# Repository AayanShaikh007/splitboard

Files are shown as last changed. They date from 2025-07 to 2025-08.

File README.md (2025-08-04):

# Splitboard
### A split keyboard modelled after the Ergodox with wireless connectivity

## What is the Splitboard?

The splitboard is a diy keyboard modelled after the Ergodox that has wireless bluetooth connectivity and on-board battery charging/management. The most striking thing about the keyboard is probably its distinct appearance compared to other keyboards, but hopefully this will add to the ergonomics of the keyboard. For this keyboard, I wanted to incorporate a number of features that I liked about my last keyboard, such as RGB lighting and Kalih hotswap sockets, while also adressing some of the issues with my last keyboard.


Typical Ergodox layout

## Why did I make the Splitboard?

I made the splitboard as a follow up to my original keyboard to address some mistakes I made in my last keyboard. Firstly, I made the case walls way too thick, at 1 cm, where in reality I only needed 2-4 mm. Additionally, I see now that the keyboard has a very large footprint on my desk and is difficult to move into a comfortable typing position. The splitboard consists of two, very portable halves that can be arranged around your desk in any way you want. Additionally, the case is much more asthetically appealing with low-profile walls (3mm) and a voronoi pattern on the bottom. Check out the product gallery to get a preview of the project.  

# Product Gallery












# BOM Table
| Item | Amount | Bought? | Cost (CAD) | Total Cost | Notes | Link |
|---|---|---|---|---|---|---|
| Adafruit Feather NRF52840 | 2 | n | 37.79 | 75.58 | | [AliExpress](https://www.aliexpress.com/item/1005009226053516.html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) |
| Switches (need 76) | 1 | n | 26.99 | 26.99 | | [Amazon](https://www.amazon.ca/Kailh-Mechanical-Keyboard-Switches-Bronze/dp/B078872V4C) |
| Kalih Sockets | 1 | n | 13.57 | 13.57 | | [AliExpress](https://www.aliexpress.com/item/1005007476614771.html) |
| Diodes | 1 | n | 11.36 | 11.36 | Possibly cheaper if bought with other stuff | [AliExpress](https://www.aliexpress.com/item/4000142272546.html) |
| SK6812mini-e | 1 | n | 8.04 | 8.04 | | [AliExpress](https://www.aliexpress.com/item/1005009217389452.html) |
| Keycaps | 1 | n | 29.99 | 29.99 | | [Amazon](https://www.amazon.ca/124-Key-Keycaps-Percent-Keyboard-Dye-Sub/dp/B09NRK5B3L) |
| PCB Manufacturing | 2 | n | 19.89 | 39.78 | $20 highway coupon (not applied) | — |
| Stabilizers | 1 | n | 7.29 | 7.29 | | [AliExpress](https://www.aliexpress.com/item/1005009141481219.html) |

| | | | | | | |
|---|---|---|---|---|---|---|
| | | | **CAD** | **USD** | | |
| **Total Cost**| | | 212.60 | 155.20  | Note: 150 USD = 204.58 CAD | |

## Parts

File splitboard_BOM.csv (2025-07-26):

Item | Amount | Bought? | Cost (CAD) | Total Cost | Notes | Link
Adafruit Feather NRF52840 | 2 | n | 37.79 | 75.58 |  | https://www.aliexpress.com/item/1005009226053516.html?src=bing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
Switches (need 76) | 1 | n | 26.99 | 26.99 |  | https://www.amazon.ca/Kailh-Mechanical-Keyboard-Switches-Bronze/dp/B078872V4C
Kalih Sockets | 1 | n | 13.57 | 13.57 |  | https://www.aliexpress.com/item/1005007476614771.html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
Diodes | 1 | n | 11.36 | 11.36 | possibly cheaper if bought with other stuff | https://www.aliexpress.com/item/4000142272546.html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
sk6812mini-e | 1 | n | 8.04 | 8.04 |  | https://www.aliexpress.com/item/1005009217389452.html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
Keycaps | 1 | n | 29.99 | 29.99 |  | https://www.amazon.ca/124-Key-Keycaps-Percent-Keyboard-Dye-Sub/dp/B09NRK5B3L?xpid=mhd-51rYrrEGe
PCB Manufacturing | 2 | n | 19.89 | 39.78 | 20 dollar highway coupon (not applied)
Stabilizers | 1 | n | 7.29 | 7.29 |  | https://www.aliexpress.com/item/1005009141481219.html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
 |  |  | CAD | USD
 |  | Total Cost | 212.60 | 155.198
 |  |  |  | Note: 150 USD = 204.58 CAD

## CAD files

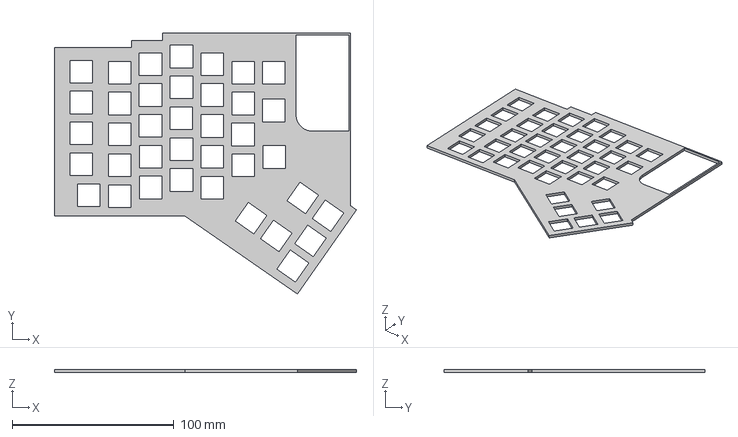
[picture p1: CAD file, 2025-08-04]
CAD/splitboard_left_top v15.step
186.5 x 161.2 x 2.00 mm

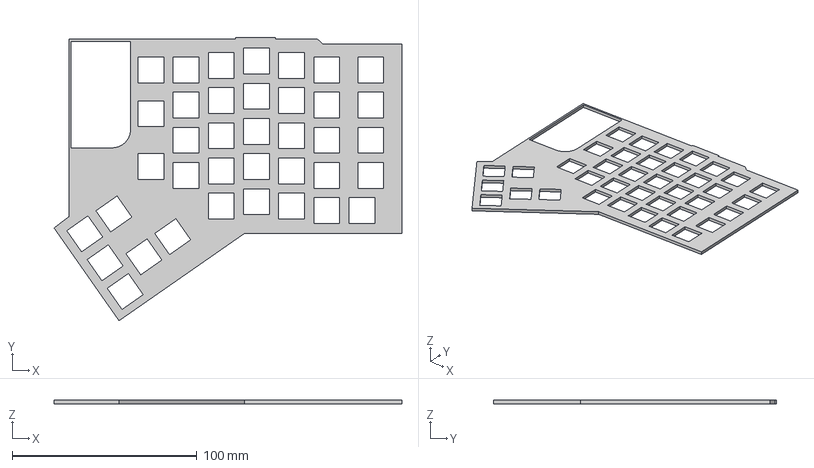
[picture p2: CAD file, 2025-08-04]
CAD/splitboard_right_top v4.step
188.5 x 153.5 x 2.00 mm

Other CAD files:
CAD/splitboard left v11.f3z
CAD/splitboard right v7.f3z

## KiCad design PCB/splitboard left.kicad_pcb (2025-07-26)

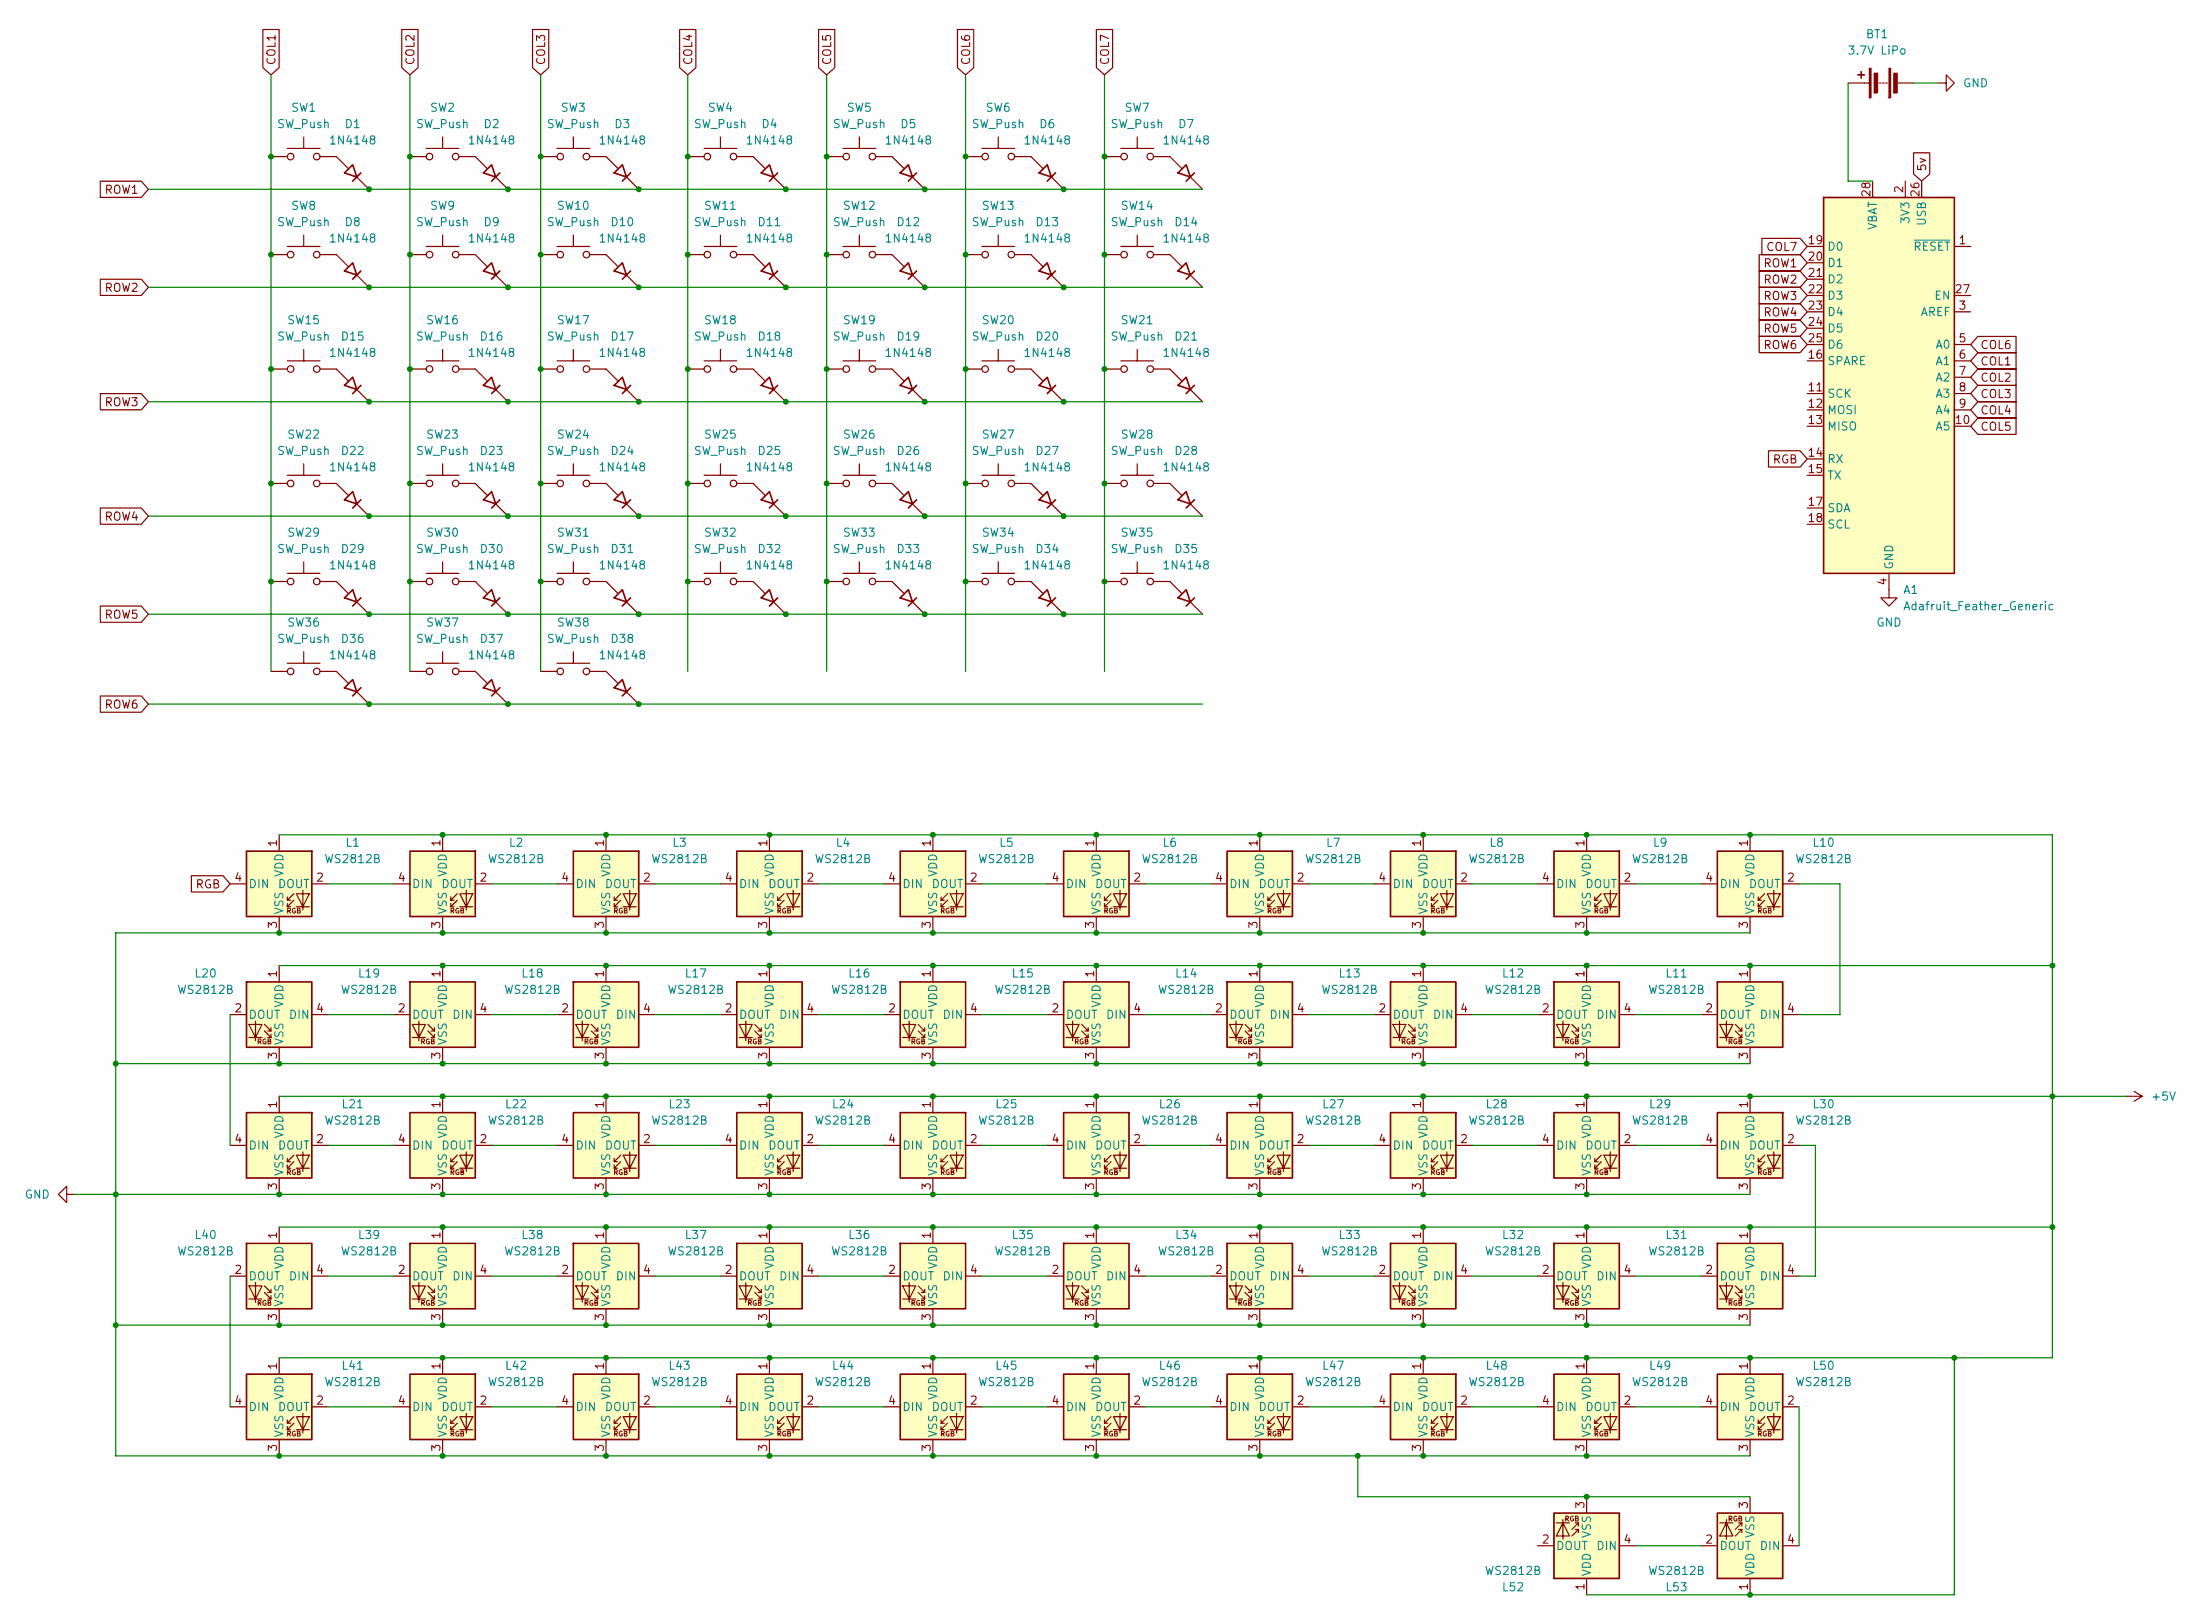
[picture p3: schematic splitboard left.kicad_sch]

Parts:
A1: Adafruit_Feather_Generic; Adafruit_Feather
BT1: 3.7V LiPo; JST_PH_S2B-PH-K_1x02_P2.00mm_Horizontal
D1, D2, D3, D4, D5, D6, D7, D8, D9, D10, D11, D12, D13, D14, D15, D16, D17, D18, D19, D20, D21, D22, D23, D24, D25, D26, D27, D28, D29, D30, D31, D32, D33, D34, D35, D36, D37, D38: 1N4148; DO35-7
L1, L2, L3, L4, L5, L6, L7, L8, L9, L10, L11, L12, L13, L14, L15, L16, L17, L18, L19, L20, L21, L22, L23, L24, L25, L26, L27, L28, L29, L30, L31, L32, L33, L34, L35, L36, L37, L38, L39, L40, L41, L42, L43, L44, L45, L46, L47, L48, L49, L50, L52, L53: WS2812B; BAcklight
SW1, SW8, SW15, SW21, SW22: SW_Push; SW_Hotswap_Kailh_MX_1.50u
SW2, SW3, SW4, SW5, SW6, SW7, SW9, SW10, SW11, SW12, SW13, SW16, SW17, SW18, SW19, SW20, SW23, SW24, SW25, SW26, SW27, SW28, SW29, SW30, SW31, SW32, SW33, SW36, SW37, SW38: SW_Push; SW_Hotswap_Kailh_MX_1.00u
SW14: SW_Push; SW_Hotswap_Kailh_MX_1.50u_90deg
SW34, SW35: SW_Push; SW_Hotswap_Kailh_MX_2.00u

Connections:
5v: A1.26 (USB)
+5V: L1.1 (VDD), L2.1 (VDD), L3.1 (VDD), L4.1 (VDD), L5.1 (VDD), L6.1 (VDD), L7.1 (VDD), L8.1 (VDD), L9.1 (VDD), L10.1 (VDD), L11.1 (VDD), L12.1 (VDD), L13.1 (VDD), L14.1 (VDD), L15.1 (VDD), L16.1 (VDD), L17.1 (VDD), L18.1 (VDD), L19.1 (VDD), L20.1 (VDD), L21.1 (VDD), L22.1 (VDD), L23.1 (VDD), L24.1 (VDD), L25.1 (VDD), L26.1 (VDD), L27.1 (VDD), L28.1 (VDD), L29.1 (VDD), L30.1 (VDD), L31.1 (VDD), L32.1 (VDD), L33.1 (VDD), L34.1 (VDD), L35.1 (VDD), L36.1 (VDD), L37.1 (VDD), L38.1 (VDD), L39.1 (VDD), L40.1 (VDD), L41.1 (VDD), L42.1 (VDD), L43.1 (VDD), L44.1 (VDD), L45.1 (VDD), L46.1 (VDD), L47.1 (VDD), L48.1 (VDD), L49.1 (VDD), L50.1 (VDD), L52.1 (VDD), L53.1 (VDD)
COL1: A1.6 (A1), SW1.1, SW8.1, SW15.1, SW22.1, SW29.1, SW36.1
COL2: A1.7 (A2), SW2.1, SW9.1, SW16.1, SW23.1, SW30.1, SW37.1
COL3: A1.8 (A3), SW3.1, SW10.1, SW17.1, SW24.1, SW31.1, SW38.1
COL4: A1.9 (A4), SW4.1, SW11.1, SW18.1, SW25.1, SW32.1
COL5: A1.10 (A5), SW5.1, SW12.1, SW19.1, SW26.1, SW33.1
COL6: A1.5 (A0), SW6.1, SW13.1, SW20.1, SW27.1, SW34.1
COL7: A1.19 (D0), SW7.1, SW14.1, SW21.1, SW28.1, SW35.1
GND: A1.4 (GND), BT1.2 (-), L1.3 (VSS), L2.3 (VSS), L3.3 (VSS), L4.3 (VSS), L5.3 (VSS), L6.3 (VSS), L7.3 (VSS), L8.3 (VSS), L9.3 (VSS), L10.3 (VSS), L11.3 (VSS), L12.3 (VSS), L13.3 (VSS), L14.3 (VSS), L15.3 (VSS), L16.3 (VSS), L17.3 (VSS), L18.3 (VSS), L19.3 (VSS), L20.3 (VSS), L21.3 (VSS), L22.3 (VSS), L23.3 (VSS), L24.3 (VSS), L25.3 (VSS), L26.3 (VSS), L27.3 (VSS), L28.3 (VSS), L29.3 (VSS), L30.3 (VSS), L31.3 (VSS), L32.3 (VSS), L33.3 (VSS), L34.3 (VSS), L35.3 (VSS), L36.3 (VSS), L37.3 (VSS), L38.3 (VSS), L39.3 (VSS), L40.3 (VSS), L41.3 (VSS), L42.3 (VSS), L43.3 (VSS), L44.3 (VSS), L45.3 (VSS), L46.3 (VSS), L47.3 (VSS), L48.3 (VSS), L49.3 (VSS), L50.3 (VSS), L52.3 (VSS), L53.3 (VSS)
unnamed: A1.28 (VBAT), BT1.1 (+)
unnamed: D1.2 (A), SW1.2
unnamed: D2.2 (A), SW2.2
unnamed: D3.2 (A), SW3.2
unnamed: D4.2 (A), SW4.2
unnamed: D5.2 (A), SW5.2
unnamed: D6.2 (A), SW6.2
unnamed: D7.2 (A), SW7.2
unnamed: D8.2 (A), SW8.2
unnamed: D9.2 (A), SW9.2
unnamed: D10.2 (A), SW10.2
unnamed: D11.2 (A), SW11.2
unnamed: D12.2 (A), SW12.2
unnamed: D13.2 (A), SW13.2
unnamed: D14.2 (A), SW14.2
unnamed: D15.2 (A), SW15.2
unnamed: D16.2 (A), SW16.2
unnamed: D17.2 (A), SW17.2
unnamed: D18.2 (A), SW18.2
unnamed: D19.2 (A), SW19.2
unnamed: D20.2 (A), SW20.2
unnamed: D21.2 (A), SW21.2
unnamed: D22.2 (A), SW22.2
unnamed: D23.2 (A), SW23.2
unnamed: D24.2 (A), SW24.2
unnamed: D25.2 (A), SW25.2
unnamed: D26.2 (A), SW26.2
unnamed: D27.2 (A), SW27.2
unnamed: D28.2 (A), SW28.2
unnamed: D29.2 (A), SW29.2
unnamed: D30.2 (A), SW30.2
unnamed: D31.2 (A), SW31.2
unnamed: D32.2 (A), SW32.2
unnamed: D33.2 (A), SW33.2
unnamed: D34.2 (A), SW34.2
unnamed: D35.2 (A), SW35.2
unnamed: D36.2 (A), SW36.2
unnamed: D37.2 (A), SW37.2
unnamed: D38.2 (A), SW38.2
unnamed: L1.2 (DOUT), L2.4 (DIN)
unnamed: L2.2 (DOUT), L3.4 (DIN)
unnamed: L3.2 (DOUT), L4.4 (DIN)
unnamed: L4.2 (DOUT), L5.4 (DIN)
unnamed: L5.2 (DOUT), L6.4 (DIN)
unnamed: L6.2 (DOUT), L7.4 (DIN)
unnamed: L7.2 (DOUT), L8.4 (DIN)
unnamed: L8.2 (DOUT), L9.4 (DIN)
unnamed: L9.2 (DOUT), L10.4 (DIN)
unnamed: L10.2 (DOUT), L11.4 (DIN)
unnamed: L11.2 (DOUT), L12.4 (DIN)
unnamed: L12.2 (DOUT), L13.4 (DIN)
unnamed: L13.2 (DOUT), L14.4 (DIN)
unnamed: L14.2 (DOUT), L15.4 (DIN)
unnamed: L15.2 (DOUT), L16.4 (DIN)
unnamed: L16.2 (DOUT), L17.4 (DIN)
unnamed: L17.2 (DOUT), L18.4 (DIN)
unnamed: L18.2 (DOUT), L19.4 (DIN)
unnamed: L19.2 (DOUT), L20.4 (DIN)
unnamed: L20.2 (DOUT), L21.4 (DIN)
unnamed: L21.2 (DOUT), L22.4 (DIN)
unnamed: L22.2 (DOUT), L23.4 (DIN)
unnamed: L23.2 (DOUT), L24.4 (DIN)
unnamed: L24.2 (DOUT), L25.4 (DIN)
unnamed: L25.2 (DOUT), L26.4 (DIN)
unnamed: L26.2 (DOUT), L27.4 (DIN)
unnamed: L27.2 (DOUT), L28.4 (DIN)
unnamed: L28.2 (DOUT), L29.4 (DIN)
unnamed: L29.2 (DOUT), L30.4 (DIN)
unnamed: L30.2 (DOUT), L31.4 (DIN)
unnamed: L31.2 (DOUT), L32.4 (DIN)
unnamed: L32.2 (DOUT), L33.4 (DIN)
unnamed: L33.2 (DOUT), L34.4 (DIN)
unnamed: L34.2 (DOUT), L35.4 (DIN)
unnamed: L35.2 (DOUT), L36.4 (DIN)
unnamed: L36.2 (DOUT), L37.4 (DIN)
unnamed: L37.2 (DOUT), L38.4 (DIN)
unnamed: L38.2 (DOUT), L39.4 (DIN)
unnamed: L39.2 (DOUT), L40.4 (DIN)
unnamed: L40.2 (DOUT), L41.4 (DIN)
unnamed: L41.2 (DOUT), L42.4 (DIN)
unnamed: L42.2 (DOUT), L43.4 (DIN)
unnamed: L43.2 (DOUT), L44.4 (DIN)
unnamed: L44.2 (DOUT), L45.4 (DIN)
unnamed: L45.2 (DOUT), L46.4 (DIN)
unnamed: L46.2 (DOUT), L47.4 (DIN)
unnamed: L47.2 (DOUT), L48.4 (DIN)
unnamed: L48.2 (DOUT), L49.4 (DIN)
unnamed: L49.2 (DOUT), L50.4 (DIN)
unnamed: L50.2 (DOUT), L53.4 (DIN)
unnamed: L52.4 (DIN), L53.2 (DOUT)
RGB: A1.14 (RX), L1.4 (DIN)
ROW1: A1.20 (D1), D1.1 (K), D2.1 (K), D3.1 (K), D4.1 (K), D5.1 (K), D6.1 (K), D7.1 (K)
ROW2: A1.21 (D2), D8.1 (K), D9.1 (K), D10.1 (K), D11.1 (K), D12.1 (K), D13.1 (K), D14.1 (K)
ROW3: A1.22 (D3), D15.1 (K), D16.1 (K), D17.1 (K), D18.1 (K), D19.1 (K), D20.1 (K), D21.1 (K)
ROW4: A1.23 (D4), D22.1 (K), D23.1 (K), D24.1 (K), D25.1 (K), D26.1 (K), D27.1 (K), D28.1 (K)
ROW5: A1.24 (D5), D29.1 (K), D30.1 (K), D31.1 (K), D32.1 (K), D33.1 (K), D34.1 (K), D35.1 (K)
ROW6: A1.25 (D6), D36.1 (K), D37.1 (K), D38.1 (K)

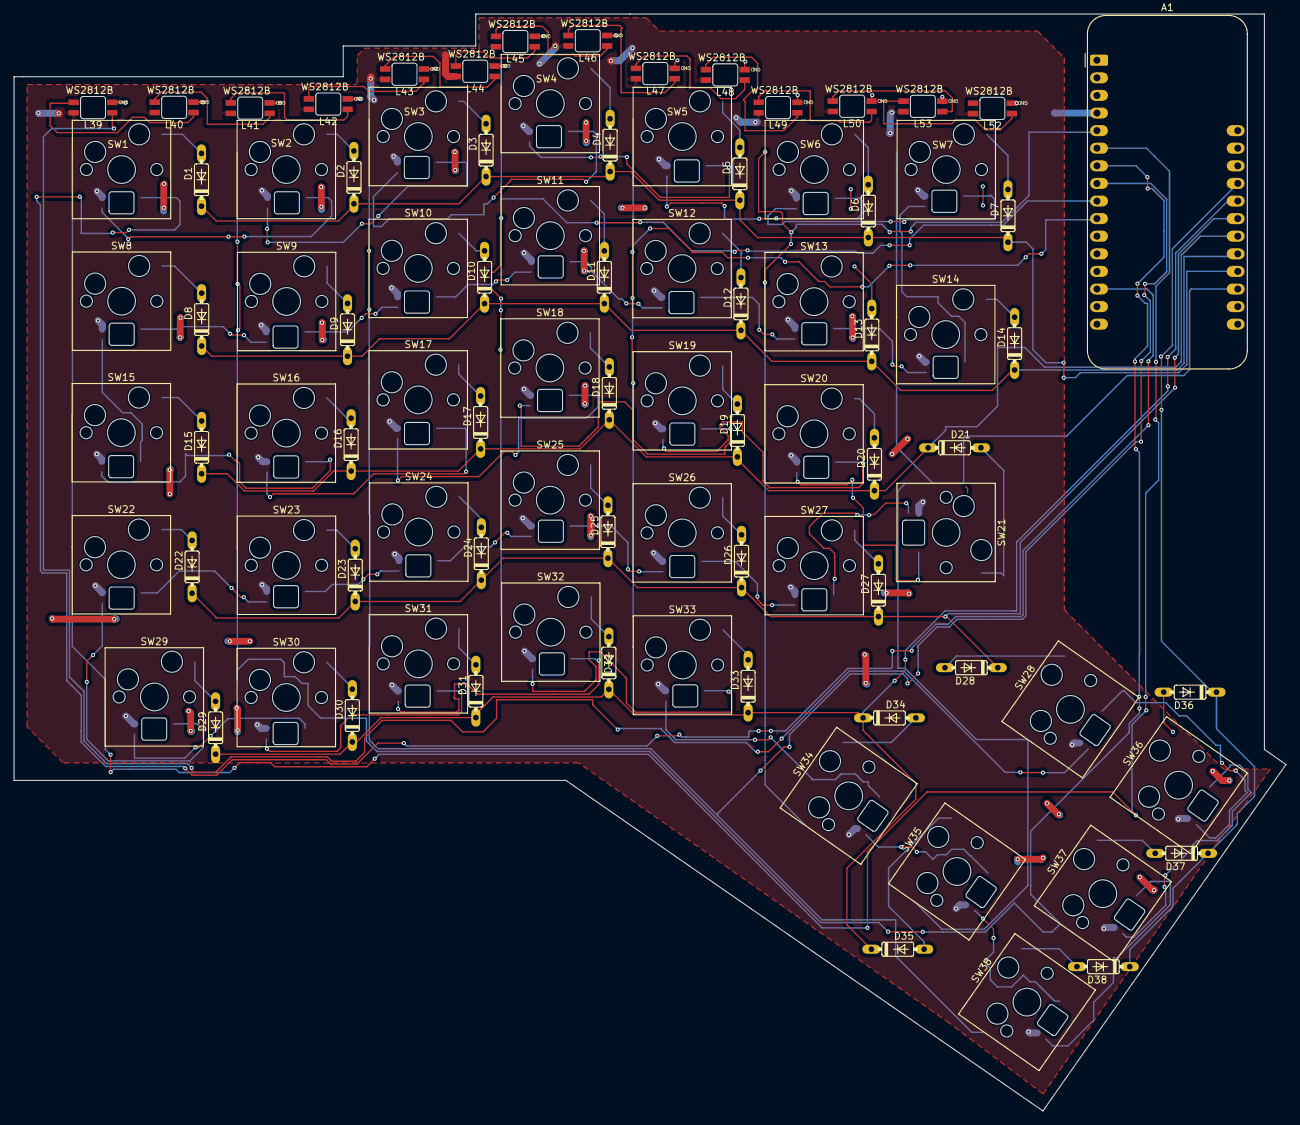
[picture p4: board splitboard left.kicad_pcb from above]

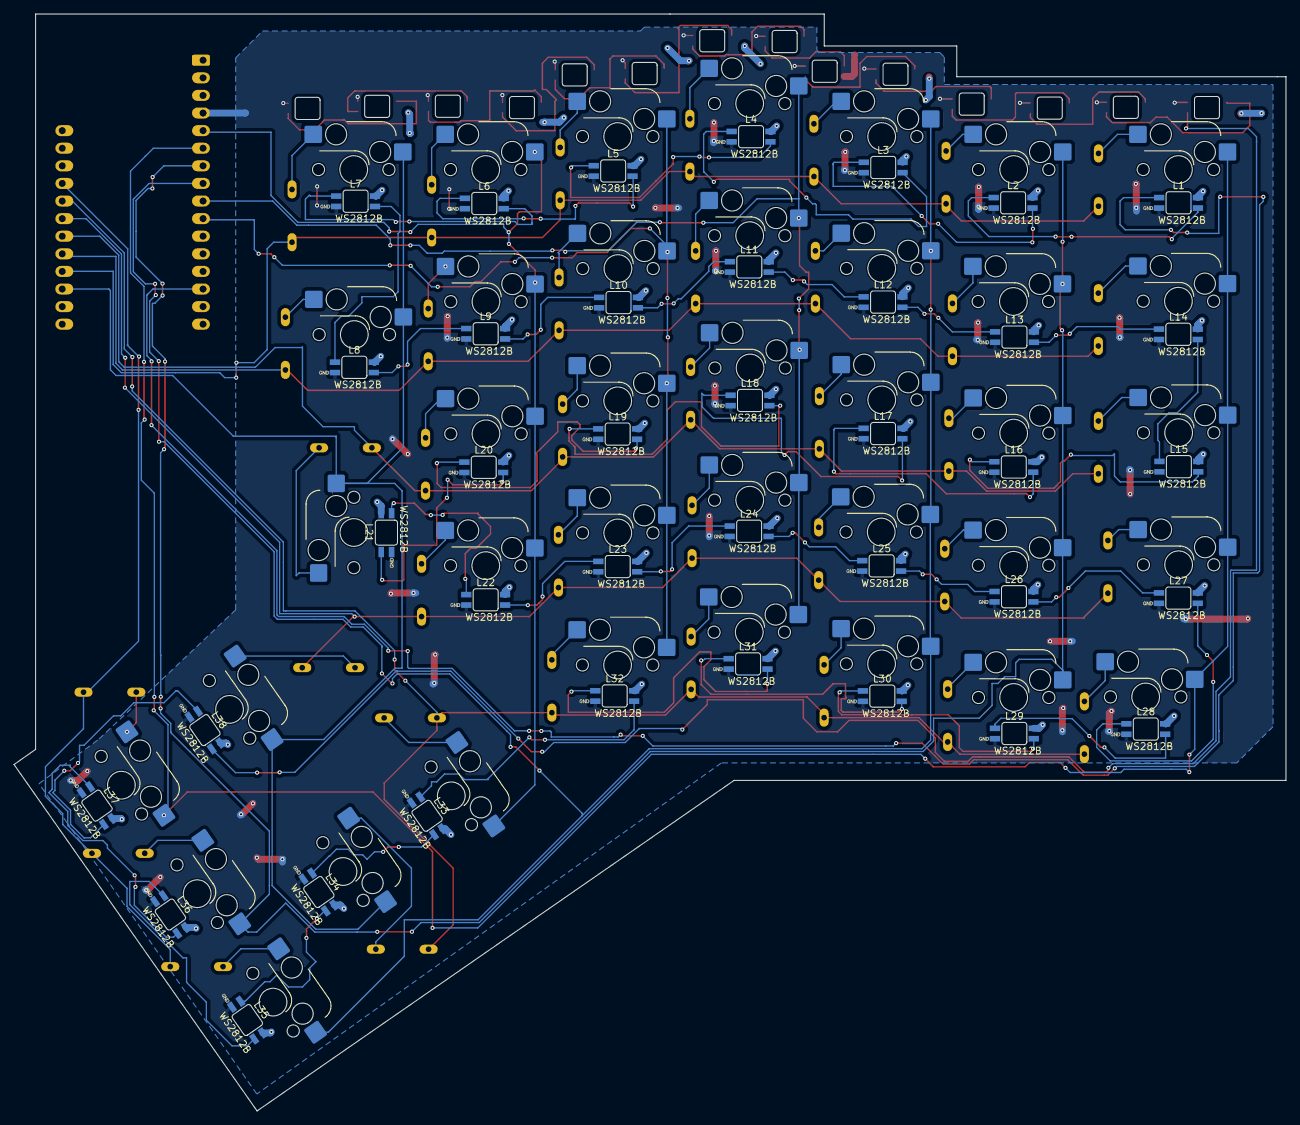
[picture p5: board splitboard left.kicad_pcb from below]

Board: 2 copper layers, 183.6 x 158.3 mm, 129 parts (38 on the bottom side), 105 nets.

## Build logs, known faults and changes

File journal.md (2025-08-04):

---
title: "splitboard"
author: "@Scalar"
description: "wireless split keyboard"
created_at: "2025-07-09"
---

# Splitboard

_**25 hours spent total**_
## July 9th, 1:17am- ~1 hour spent

Officially begin splitboard. But before that, the project description- splitboard is a hotswappable keyboard that I will be making to address issues in my last keyboard, scalars-keyboard (also on my github profile). 

- Firstly, I completely underestimated the size of the keyboard and what should have been a mid-sized keyboard came out to be bigger than the keyboard i have on my laptop. **Compact form factor is a major element of this project.**
- Next, Ive wanted to try a wireless keyboard design ever since the pico W got bluetooth connectivity. **Wireless connectivity is a must.** Therefore, I need to handle **bluetooth connectivity** and how to **power the board using a battery**. 
- Finally, I want to try a **split keyboard design** for this keyboard for ergonomics.

In my research, I found out about a keyboard called the ergodox. I will aim for a design similar to it, but I intend to add two other unique elements:
- ~~A mini trackpad (similar to a thinkpad)~~ I decided not to add this as the trackball will be take its functionality. 
- A trackball (to navigate menus and 3d softwares). 

I will also try to add some sort of backlight similar to the original.


# July 9th, 2:04am- 1 hour spent planning and researching parts. 
With that out of the way, I will now begin with a rough design from a online configurator. 

Left Half: 38 total switches



Right half: 32 total switches



Since the left half is simpler, I will start making the pcb for it. **I will need to make the entire trackball assembly for the right side.**

The microcontroller I chose to work with is a Adafruit Feather nRF52840 Express, because of its bluetooth connectivity and power management / battery charging support. 

# July 20th- 3 hours spent
I had to take a break from the project due to undercity. Today, I worked with other hack clubbers to collectively finish/work on our keyboards. I took the opportunity to finalize a Kicad schematic and gather all required footprints for the project. 


Schematic for splitboard left. 

With this done, I will now work on the PCB of the board. 

# July 21st- 2 hours spent
Today, I decided to begin the PCB design of the board. I spent around 2 hours arranging the keyswitch footprints to their correct locations. Kicad was acting funny again just like with the last keyboard. Tomorrow I will arrange the LEDs and do the same with the splitboard right. I am also thinking about removing the trackball from the keyboard and making it into its own entity (a seperate pcb). I will focus on this later. 



# July 22nd- 4-5 hours spent
Finished wiring most of the left splitboard and arranged all parts for both the left and right splitboard other than the microcontroller. 



# July 24th- Spent 4 hours on PCB
Finished wiring the right keyboard and whatever was left of the left splitboard. 



# July 25th- Spent 6 hours on the case
Finished designing the case for the left and right splitboard, hence concluding the project. I decided to go with a voronoi pattern on the bottom of the case to add some originality and appeal to it. Produced the BOM. 



# August 4th- Spent 3 hours editing the case
I added the physical models of some switches and a low poly rectangle with the exact dimensions of the battery I have at home that should work with the microcontroller used in this keyboard. This proved to be pretty helpful since it revealed a mistake in my top plates, and although tedious to resolve, I was able to fix all issues. Everything should fit nicely, hopefully. 





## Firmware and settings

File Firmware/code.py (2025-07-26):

import board
import busio

from kmk.kmk_keyboard import KMKKeyboard
from kmk.keys import KC
from kmk.scanners import DiodeOrientation
from kmk.modules.macros import Macros

keyboard = KMKKeyboard()

# from kmk.extensions.display import Display, TextEntry
# from kmk.extensions.LED import LED, AnimationModes
# from kmk.extensions.display.ssd1306 import SSD1306

from kmk.modules.encoder import EncoderHandler

encoder_handler = EncoderHandler()
keyboard.modules = [encoder_handler]

from kmk.extensions.media_keys import MediaKeys
keyboard.extensions.append(MediaKeys())


col_0 = board.GP0  # Column0
col_1 = board.GP1  # Column1
col_2 = board.GP8  # Column2
col_3 = board.GP9  # Column3
col_4 = board.GP12 # Column4
col_5 = board.GP13 # Column5
col_6 = board.GP16 # Column6
col_7 = board.GP17 # Column7
col_8 = board.GP26


row_0 = board.GP2
row_1 = board.GP3
row_2 = board.GP6
row_3 = board.GP7
row_4 = board.GP10
row_5 = board.GP11
row_6 = board.GP14
row_7 = board.GP15
row_8 = board.GP18
row_9 = board.GP19

keyboard.diode_orientation = DiodeOrientation.COL2ROW # the stripe (+) points towards the row 

keyboard.col_pins = (col_0, col_1, col_2, col_3, col_4, col_5, col_6, col_7, col_8);
keyboard.row_pins = (row_0, row_1, row_2, row_3, row_4, row_5, row_6, row_7, row_8, row_9);


keyboard.keymap = [
    [KC.ESC, KC.KP_ASTERISK, KC.F1, KC.F2, KC.F3, KC.F4, KC.F5, KC.F6, KC.F7, KC.F8, KC.F9, KC.F10, KC.F11, KC.F12, KC.PSCREEN, KC.DELETE, KC.KP_4, KC.KP_5, KC.KP_6, KC.KP_3, KC.KP_2, KC.KP_1, KC.N8, KC.N9, KC.N0, KC.MINUS, KC.EQUAL, KC.RBRACKET, KC.GRAVE, KC.N1, KC.N2, KC.N3, KC.N4, KC.N5, KC.N6, KC.N7, KC.Q, KC.W, KC.E, KC.R, KC.T, KC.Y, KC.U, KC.I, KC.O, KC.A, KC.S, KC.D, KC.F, KC.G, KC.H, KC.J, KC.K, KC.L, KC.Z, KC.X, KC.C, KC.V, KC.B, KC.N, KC.M, KC.COMMA, KC.DOT, KC.P, KC.LBRACKET, KC.SCOLON, KC.QUOTE, KC.SLASH, KC.LALT, KC.LEFT, KC.DOWN, KC.RIGHT, KC.KP_7, KC.UP, KC.KP_9, KC.LCTRL, KC.LGUI, KC.RALT, KC.RGUI, KC.RCTRL, KC.TAB, KC.BSLASH, KC.MENU, KC.CAPSLOCK, KC.BSPC, KC.ENTER, KC.LSHIFT, KC.RSHIFT, KC.SPACE, KC.VOLU],  # Row 0
    [KC.F9, KC.F10, KC.F11, KC.F12, KC.PSCREEN, KC.GRAVE, KC.N1, KC.N2, KC.N3],  # row 1 test
    [KC.F1]*9,
    [KC.NO, KC.N1, KC.N2, KC.N3, KC.N4, KC.N5, KC.NO, KC.NO, KC.NO],
    [KC.F2]*9,
    [KC.F3]*9,
    [KC.F4]*9,
    [KC.F5]*9,
    [KC.F6]*9,
    [KC.F7]*9,
]




encoder_handler = EncoderHandler()

encoder_handler.pins = ((board.GP22, board.GP20, None),)


encoder_handler.map = [
    ((KC.VOLD, KC.VOLU, KC.MUTE),), 
]


if __name__ == '__main__':
    keyboard.go()





# d_pin = board.GP8

# oled_bus = busio.I2C(board.GP_SCL, board.GP_SDA)

# oled_driver = SSD1306(i2c=oled_bus, device_address=0x3C);

# display = Display(
#     display=oled_driver,
#     width=128,
#     height=32, 
#     dim_time=10,
#     dim_target=0.2,
#     off_time=1200,
#     brightness=0.8
# );

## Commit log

2025-07-26 final changes
    [splitboard left-B_Cu.gbr, splitboard left-B_Mask.gbr, splitboard left-B_Paste.gbr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]
2025-08-04 final commit ???
    [splitboard left v11.f3z, splitboard right v7.f3z, splitboard_left_top v15.step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]
